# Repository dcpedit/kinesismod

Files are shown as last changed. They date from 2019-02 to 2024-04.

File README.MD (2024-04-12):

# Project moved to [Pillz Mod](https://github.com/dcpedit/pillzmod)
<p align="center">
  
</p>

This project has been replaced by Pillz Mod: https://github.com/dcpedit/pillzmod

# Kinesis Stapelberg Mod in KiCAD

kinesis-4

This is a fork of Aaron Silman's [kinesismod project](https://gitlab.com/Silman/kinesismod.git).  You can read more about it [on his blog](https://silman.io/project/kinesis_mod/)

This fork contains the following changes:

* Created a version that uses the Teensy 4.x
* Created a version that uses the STM32F411 Blackpill controller (`blackpill` directory)
* Use Vial firmware (`firmware` directory).
* Use ZMK firmware (`firmware` directory) wireless PillBug BLE option.

## USB Port

I recommend purchasing the following adapter from Amazon:
https://a.co/d/cRoqHqx

Here's how it looks like after installing:





## Wireless Bluetooth + ZMK
Bluetooth has been verified to work using the PillBug development board.  Below, you can see a 2000mAh 3.7V battery ([Amazon link](https://a.co/d/dVUdHxi)), as well as a 10mm push button ([Amazon link](https://a.co/d/5OVO4dY)) to disconnect the power when needed.



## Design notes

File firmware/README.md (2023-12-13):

# Firmware

## Vial (for Blackpill controller)
https://get.vial.today

Firmware source:
https://github.com/dcpedit/vial-qmk-dev/tree/vial/keyboards/dcpedit/kint_bp

File:
* `dcpedit_kint_bp_vial.bin`

## ZMK (for PillBug controller)
PillBug BLE development board:
https://mechwild.com/product/pillbug/

Firmware source:
https://github.com/dcpedit/zmk/tree/kinesispb/app/boards/shields/kinesispb

Files:
* `zmk_default.uf2` - Default keymap (stock Kinesis)
* `zmk_reset.uf2` - Resets PillBug board for BT connectivity issue on MacOS

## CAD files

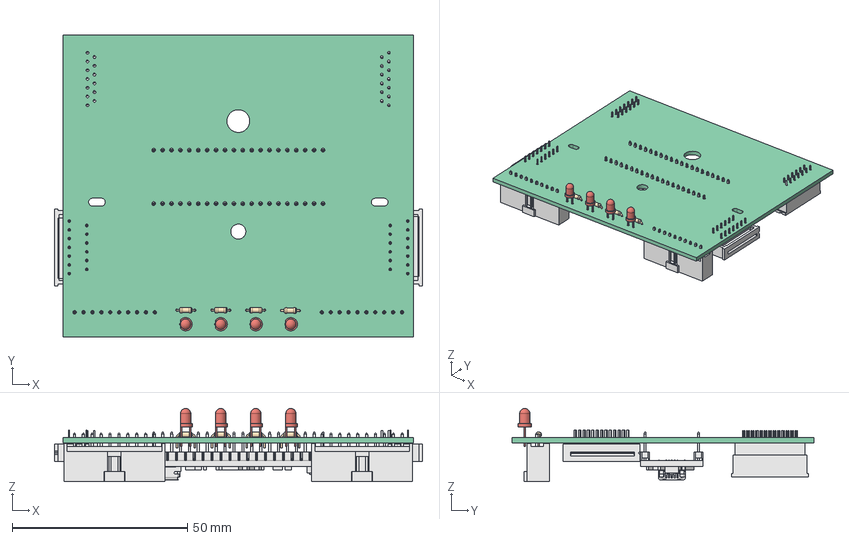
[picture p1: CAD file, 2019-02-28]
KinesisMod/board_model_FreeCAD.FCStd
104.9 x 86.0 x 20.9 mm
Pcb
D1_LED_D3.0mm_5C785324
D2_LED_D3.0mm_5C785337
D3_LED_D3.0mm_5C78534A
D4_LED_D3.0mm_5C78535D
R1_R_Axial_DIN0204_L36mm_D16mm_P508mm_Horizontal_5C785370
R2_R_Axial_DIN0204_L36mm_D16mm_P508mm_Horizontal_5C785383
R3_R_Axial_DIN0204_L36mm_D16mm_P508mm_Horizontal_5C785396
R4_R_Axial_DIN0204_L36mm_D16mm_P508mm_Horizontal_5C7853A9
J4_039532134_5C71893A
J3_039532134_5C718920
J1_039532135_5C7188EC
J2_039532135_5C718906
U1_Teensy++2.0_5C7189F9
J5_901361110_5C718957[2]
J6_901361110_5C718974[2]

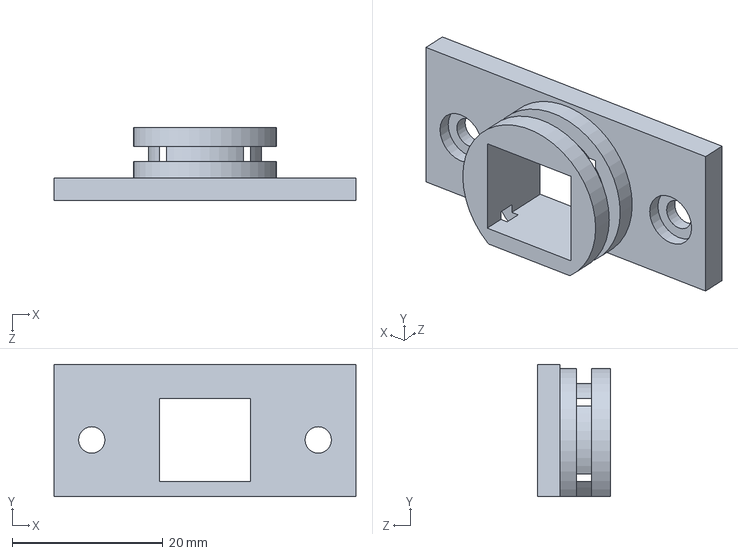
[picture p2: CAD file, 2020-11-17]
model/kinesis_usb_mount_with_reset.SLDPRT
40.0 x 17.5 x 9.70 mm

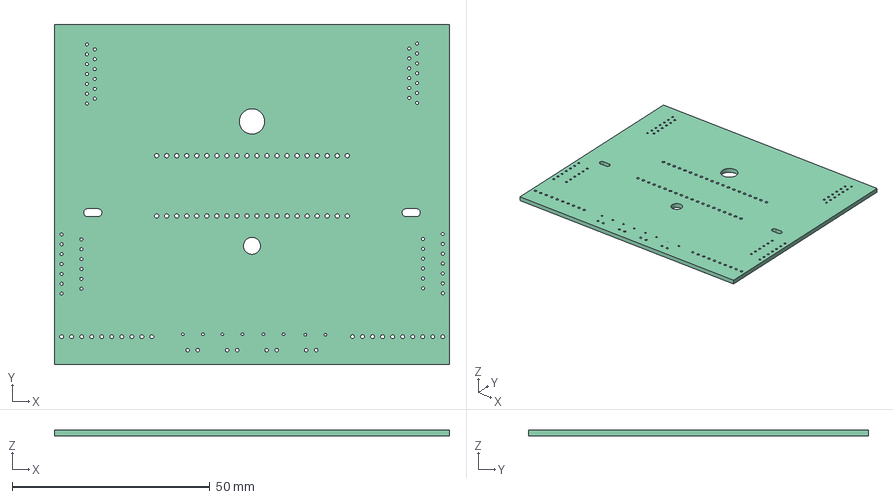
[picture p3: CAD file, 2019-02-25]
KinesisMod/boardModel.step
100.0 x 86.0 x 1.60 mm
Pcb
PCB_Sketch
Top

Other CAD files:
model/kinesis_usb_mount.SLDPRT
model/kinesis_ush_mount.STL
KinesisMod/boardModel.stl

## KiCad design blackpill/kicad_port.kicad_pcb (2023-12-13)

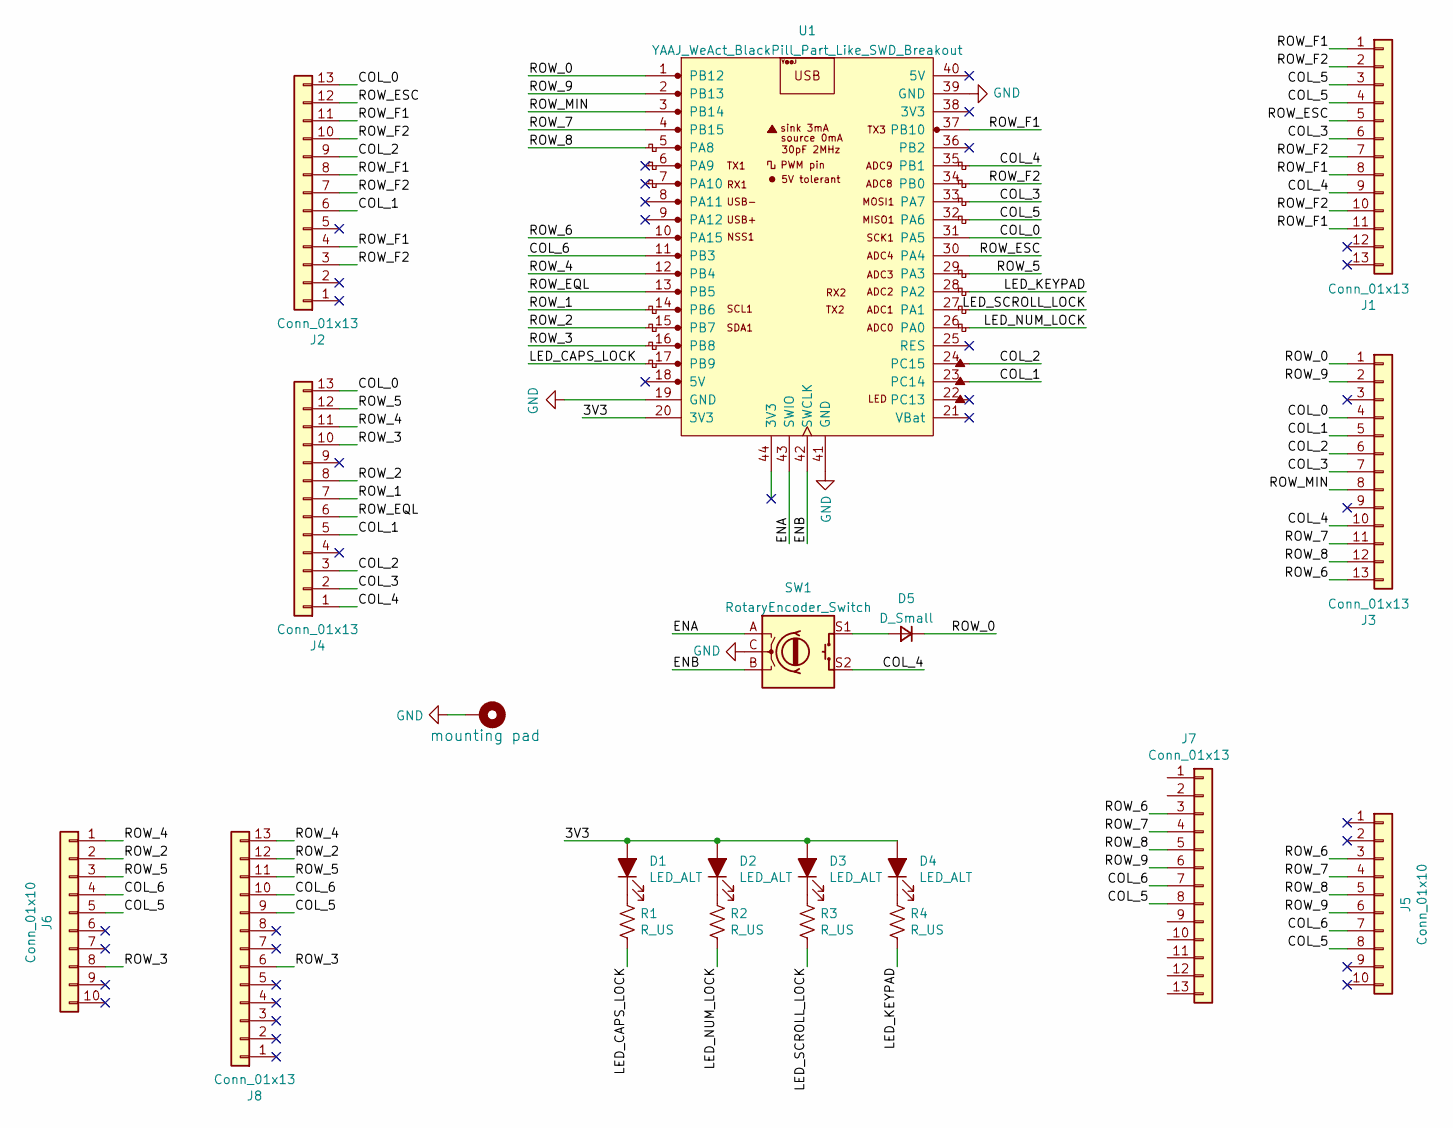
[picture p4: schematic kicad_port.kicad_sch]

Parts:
D1, D2, D3, D4: LED_ALT; LED_D3.0mm
D5: D_Small
H1: mounting pad; MountingHole_4.3mm_M4_Pad
J1, J2, J7, J8: Conn_01x13; Molex_0039532135
J3, J4: Conn_01x13; Molex_039532134
J5, J6: Conn_01x10; Pin_Header_Straight_1x10_Pitch2.54mm
R1, R2, R3, R4: R_US; R_Axial_DIN0204_L3.6mm_D1.6mm_P5.08mm_Horizontal
SW1: RotaryEncoder_Switch
U1: YAAJ_WeAct_BlackPill_Part_Like_SWD_Breakout; YAAJ_WeAct_BlackPill_SWD_2

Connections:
/3V3: D1.2 (A), D2.2 (A), D3.2 (A), D4.2 (A), U1.20 (3V3)
/COL_0: J2.13, J3.4, J4.13, U1.31 (PA5)
/COL_1: J2.6, J3.5, J4.5, U1.23 (PC14)
/COL_2: J2.9, J3.6, J4.3, U1.24 (PC15)
/COL_3: J1.6, J3.7, J4.2, U1.33 (PA7)
/COL_4: J1.9, J3.10, J4.1, SW1.S2, U1.35 (PB1)
/COL_5: J1.3, J1.4, J5.8, J6.5, J7.8, J8.9, U1.32 (PA6)
/COL_6: J5.7, J6.4, J7.7, J8.10, U1.11 (PB3)
/ENA: SW1.A, U1.43 (SWIO)
/ENB: SW1.B, U1.42 (SWCLK)
/LED_CAPS_LOCK: R1.2, U1.17 (PB9)
/LED_KEYPAD: R4.2, U1.28 (PA2)
/LED_NUM_LOCK: R2.2, U1.26 (PA0)
/LED_SCROLL_LOCK: R3.2, U1.27 (PA1)
/ROW_0: D5.1 (K), J3.1, U1.1 (PB12)
/ROW_1: J4.7, U1.14 (PB6)
/ROW_2: J4.8, J6.2, J8.12, U1.15 (PB7)
/ROW_3: J4.10, J6.8, J8.6, U1.16 (PB8)
/ROW_4: J4.11, J6.1, J8.13, U1.12 (PB4)
/ROW_5: J4.12, J6.3, J8.11, U1.29 (PA3)
/ROW_6: J3.13, J5.3, J7.3, U1.10 (PA15)
/ROW_7: J3.11, J5.4, J7.4, U1.4 (PB15)
/ROW_8: J3.12, J5.5, J7.5, U1.5 (PA8)
/ROW_9: J3.2, J5.6, J7.6, U1.2 (PB13)
/ROW_EQL: J4.6, U1.13 (PB5)
/ROW_ESC: J1.5, J2.12, U1.30 (PA4)
/ROW_F1: J1.1, J1.8, J1.11, J2.4, J2.8, J2.11, U1.37 (PB10)
/ROW_F2: J1.2, J1.7, J1.10, J2.3, J2.7, J2.10, U1.34 (PB0)
/ROW_MIN: J3.8, U1.3 (PB14)
GND: H1.1, SW1.C, U1.19 (GND), U1.39 (GND), U1.41 (GND)
unnamed: D1.1 (K), R1.1
unnamed: D2.1 (K), R2.1
unnamed: D3.1 (K), R3.1
unnamed: D4.1 (K), R4.1
unnamed: D5.2 (A), SW1.S1

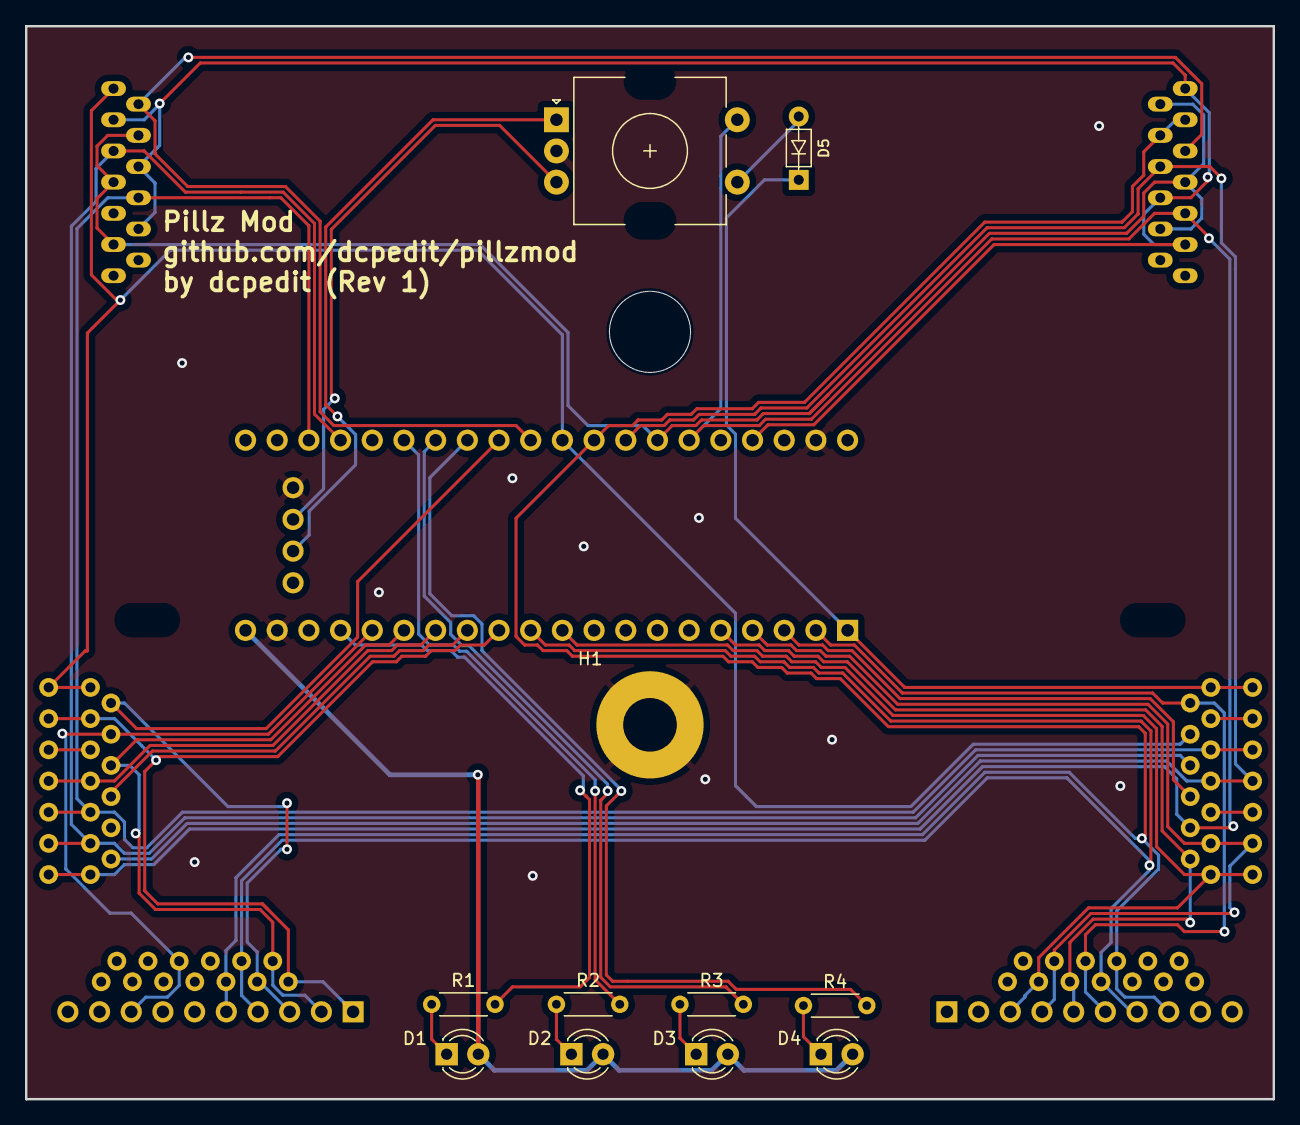
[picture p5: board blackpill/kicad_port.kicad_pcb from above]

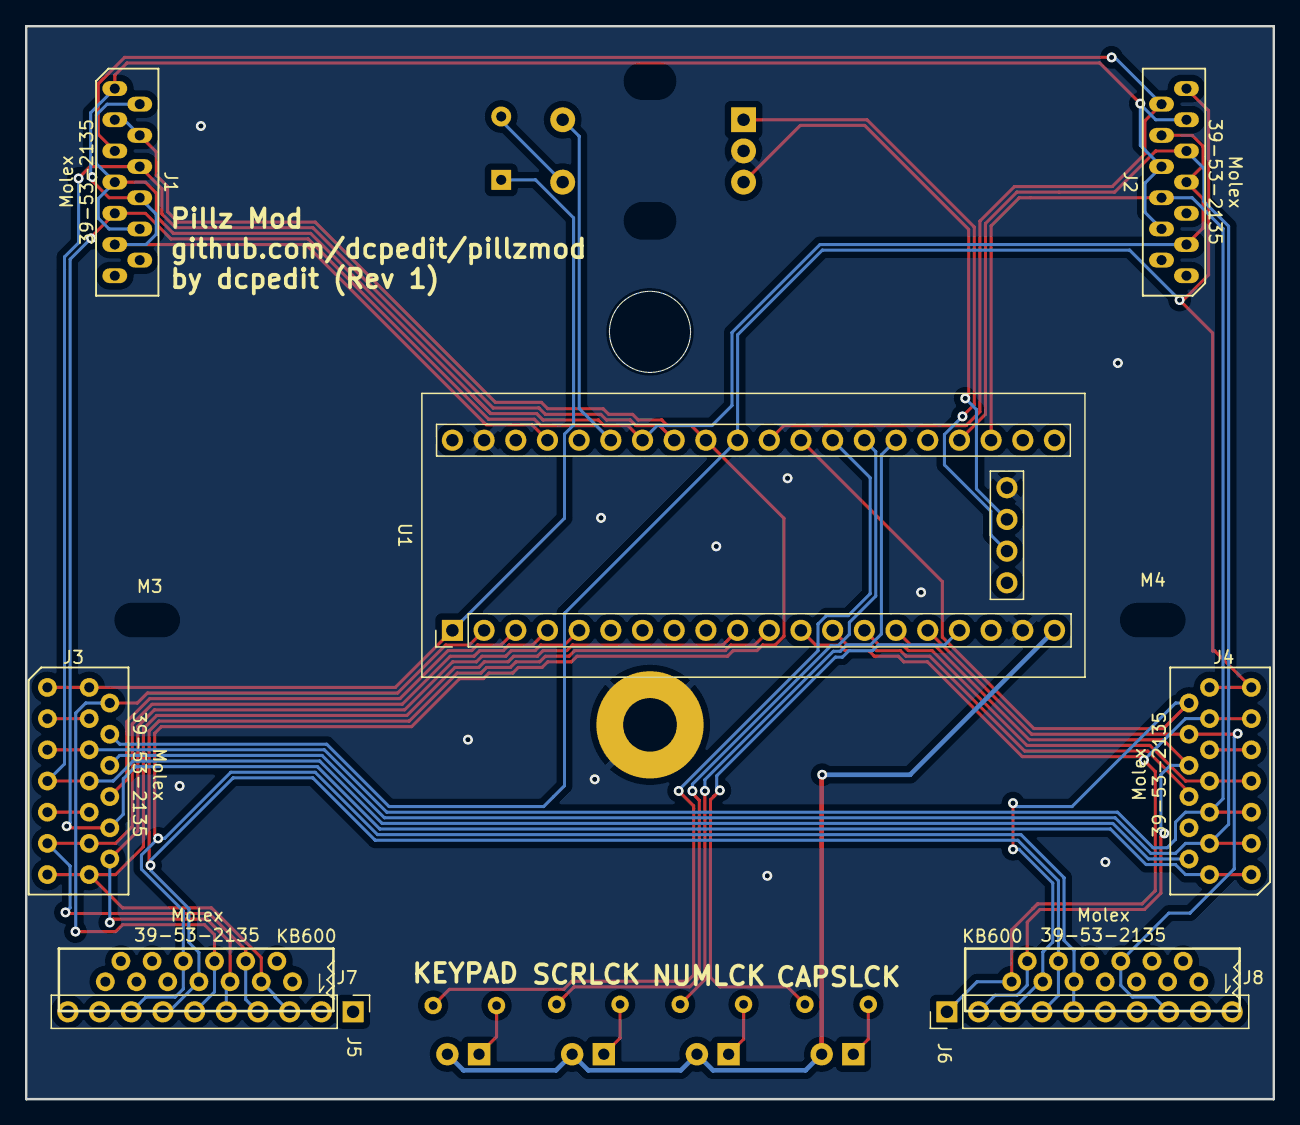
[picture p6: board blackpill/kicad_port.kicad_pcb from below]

Board: 2 copper layers, 100.0 x 86.0 mm, 23 parts (12 on the bottom side), 35 nets.

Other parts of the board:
M1: MountingHole_6.4mm_M6
M3, M4: MountingHole_4.3mm_M4

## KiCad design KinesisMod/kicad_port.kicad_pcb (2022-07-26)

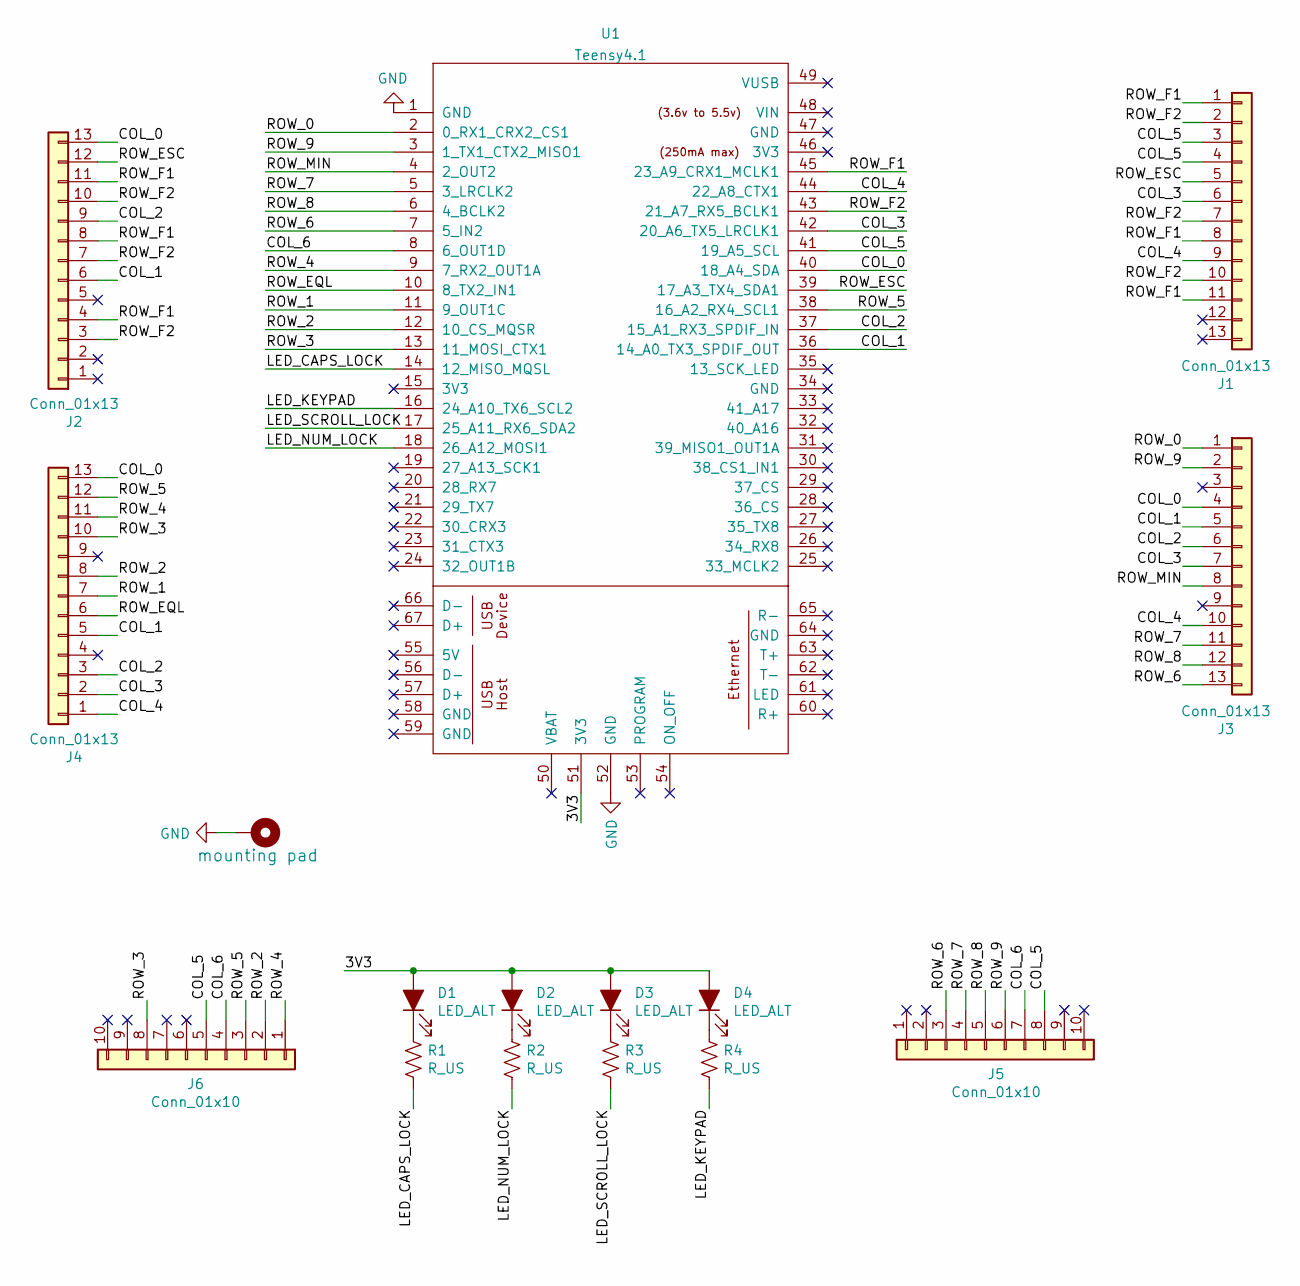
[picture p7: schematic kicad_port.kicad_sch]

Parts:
D1, D2, D3, D4: LED_ALT; LED_D3.0mm
H1: mounting pad; MountingHole_4.3mm_M4_Pad
J1, J2: Conn_01x13; Molex_0039532135
J3, J4: Conn_01x13; Molex_039532134
J5, J6: Conn_01x10; Pin_Header_Straight_1x10_Pitch2.54mm
R1, R2, R3, R4: R_US; R_Axial_DIN0204_L3.6mm_D1.6mm_P5.08mm_Horizontal
U1: Teensy4.1; Teensy41

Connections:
/3V3: D1.2 (A), D2.2 (A), D3.2 (A), D4.2 (A), U1.51 (3V3)
/COL_0: J2.13, J3.4, J4.13, U1.40 (18_A4_SDA)
/COL_1: J2.6, J3.5, J4.5, U1.36 (14_A0_TX3_SPDIF_OUT)
/COL_2: J2.9, J3.6, J4.3, U1.37 (15_A1_RX3_SPDIF_IN)
/COL_3: J1.6, J3.7, J4.2, U1.42 (20_A6_TX5_LRCLK1)
/COL_4: J1.9, J3.10, J4.1, U1.44 (22_A8_CTX1)
/COL_5: J1.3, J1.4, J5.8, J6.5, U1.41 (19_A5_SCL)
/COL_6: J5.7, J6.4, U1.8 (6_OUT1D)
/LED_CAPS_LOCK: R1.2, U1.14 (12_MISO_MQSL)
/LED_KEYPAD: R4.2, U1.16 (24_A10_TX6_SCL2)
/LED_NUM_LOCK: R2.2, U1.18 (26_A12_MOSI1)
/LED_SCROLL_LOCK: R3.2, U1.17 (25_A11_RX6_SDA2)
/ROW_0: J3.1, U1.2 (0_RX1_CRX2_CS1)
/ROW_1: J4.7, U1.11 (9_OUT1C)
/ROW_2: J4.8, J6.2, U1.12 (10_CS_MQSR)
/ROW_3: J4.10, J6.8, U1.13 (11_MOSI_CTX1)
/ROW_4: J4.11, J6.1, U1.9 (7_RX2_OUT1A)
/ROW_5: J4.12, J6.3, U1.38 (16_A2_RX4_SCL1)
/ROW_6: J3.13, J5.3, U1.7 (5_IN2)
/ROW_7: J3.11, J5.4, U1.5 (3_LRCLK2)
/ROW_8: J3.12, J5.5, U1.6 (4_BCLK2)
/ROW_9: J3.2, J5.6, U1.3 (1_TX1_CTX2_MISO1)
/ROW_EQL: J4.6, U1.10 (8_TX2_IN1)
/ROW_ESC: J1.5, J2.12, U1.39 (17_A3_TX4_SDA1)
/ROW_F1: J1.1, J1.8, J1.11, J2.4, J2.8, J2.11, U1.45 (23_A9_CRX1_MCLK1)
/ROW_F2: J1.2, J1.7, J1.10, J2.3, J2.7, J2.10, U1.43 (21_A7_RX5_BCLK1)
/ROW_MIN: J3.8, U1.4 (2_OUT2)
GND: H1.1, U1.1 (GND), U1.52 (GND)
unnamed: D1.1 (K), R1.1
unnamed: D2.1 (K), R2.1
unnamed: D3.1 (K), R3.1
unnamed: D4.1 (K), R4.1

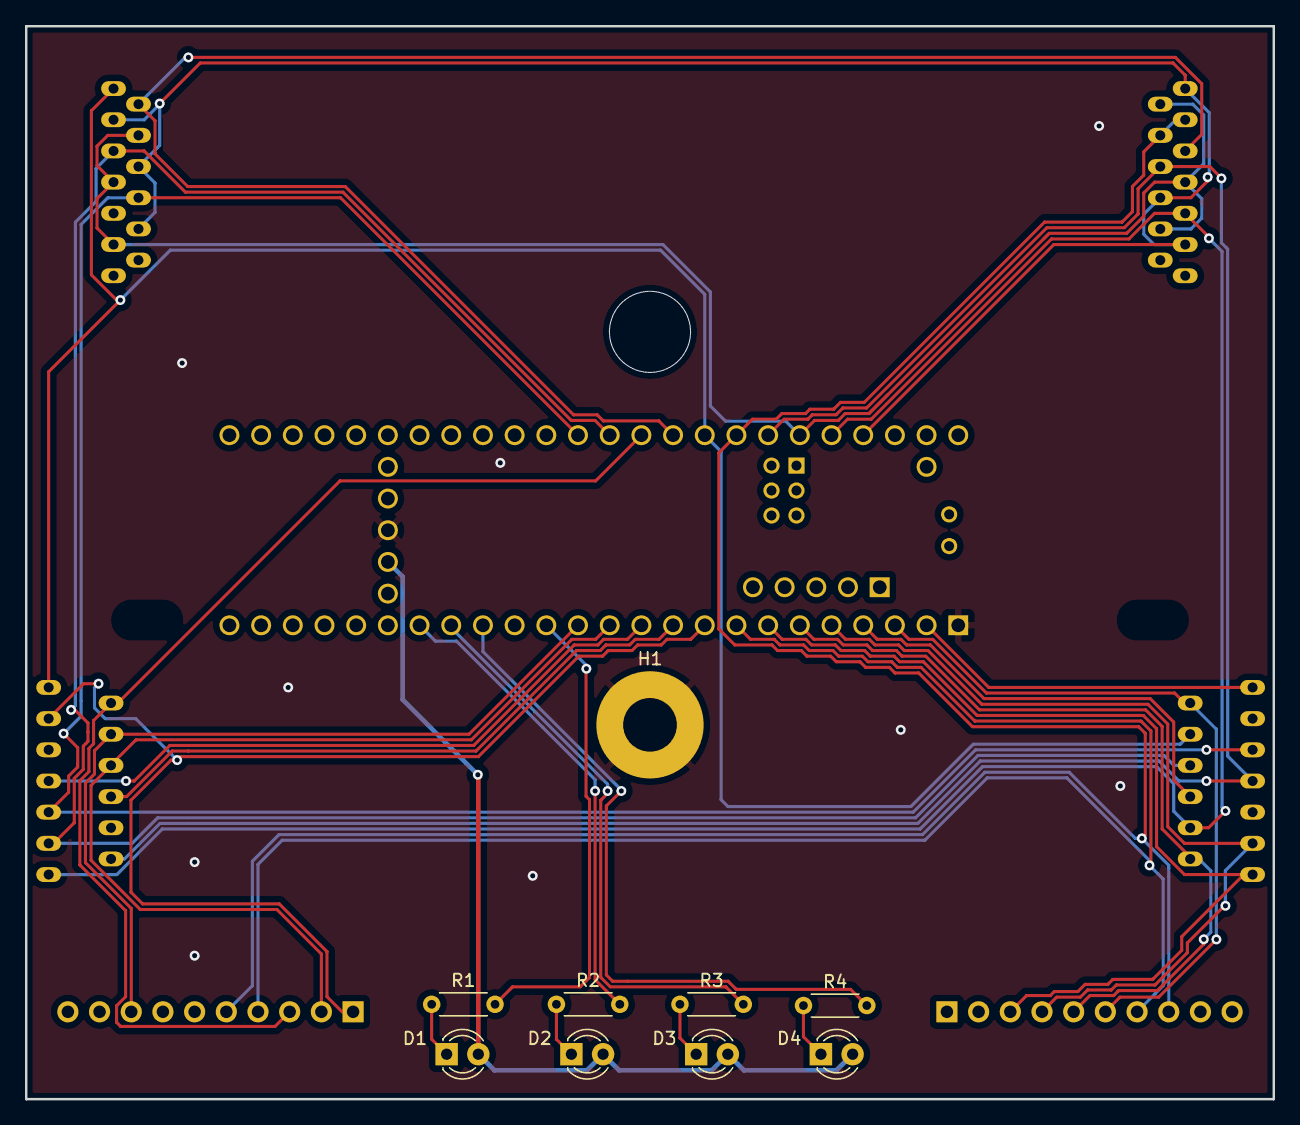
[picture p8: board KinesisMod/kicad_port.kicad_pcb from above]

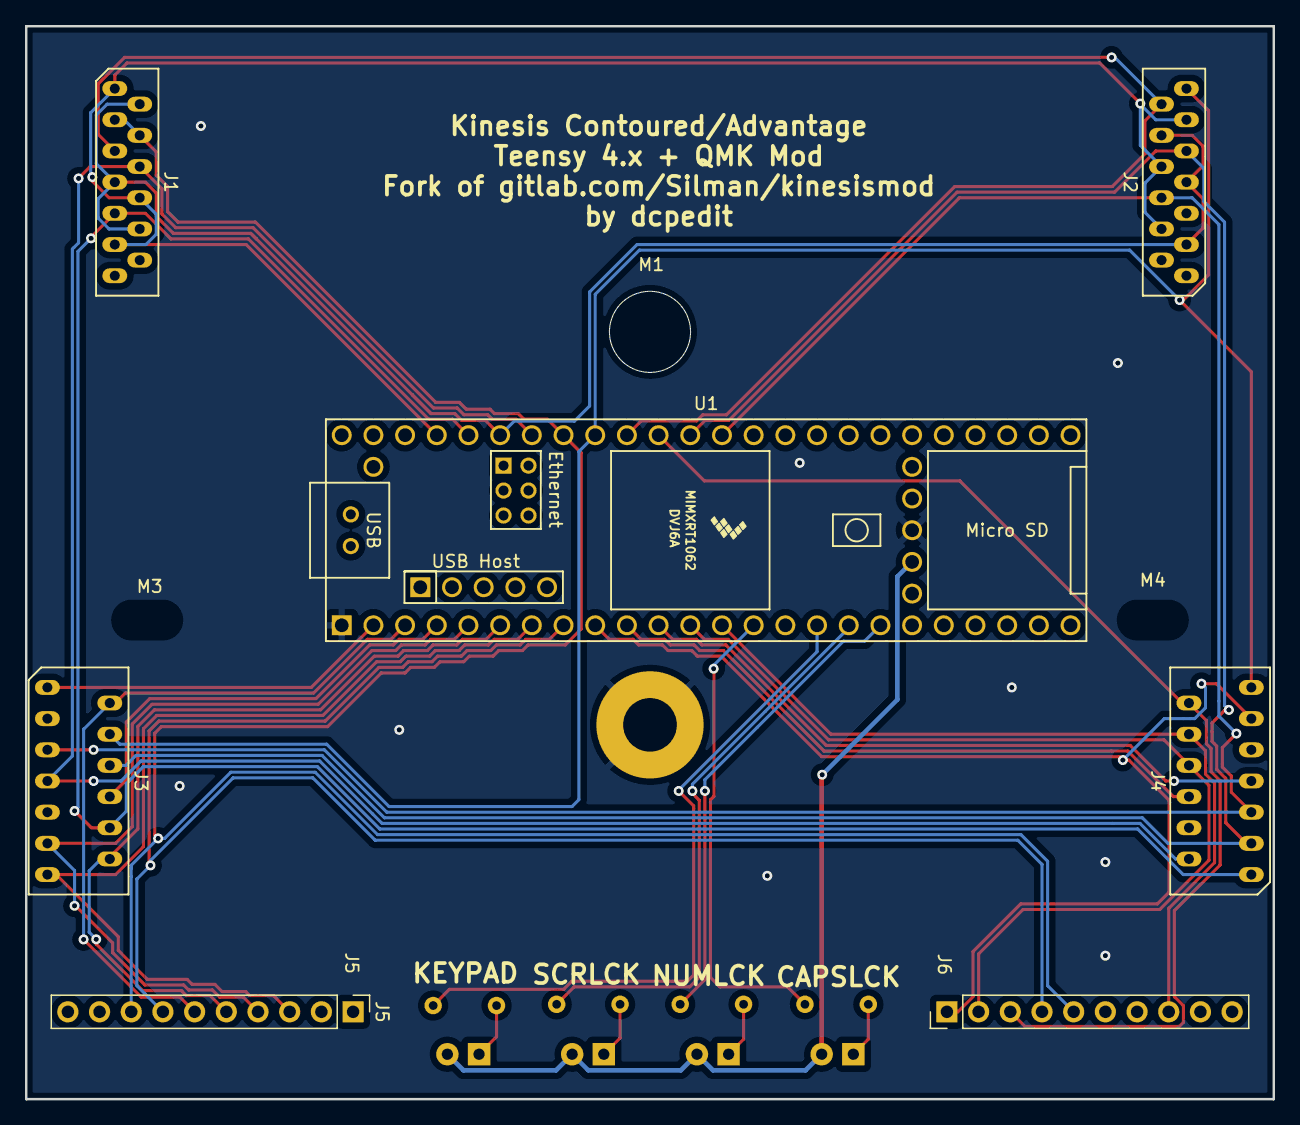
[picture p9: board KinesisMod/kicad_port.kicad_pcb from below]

Board: 2 copper layers, 100.0 x 86.0 mm, 19 parts (10 on the bottom side), 32 nets.

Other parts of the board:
M1: MountingHole_6.4mm_M6
M3, M4: MountingHole_4.3mm_M4

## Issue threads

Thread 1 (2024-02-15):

Adding extra more buttons to your version?

LeoMegaAir, 2024-02-15:
Hi dcpedit, I'm new to all this so please bear with me.

_This is not an issue_, it's a question but I couldn't find a way to ask a question here. My Kinesis has seven extra buttons (the original Kinesis controller has some extra lines so [all people do it](https://geekhack.org/index.php?topic=36195.msg2252517#msg2252517)).

Would it be possible to retain those extra buttons if I get rid of the original controller and use yours?
Another question would be, the [blackpill folder](https://github.com/dcpedit/kinesismod/tree/master/blackpill) contains so many files - which of them am I supposed to use to order a PCB on JLCPCB?

dcpedit, 2024-02-15:
The [kinesismod_blackpill.zip](https://github.com/dcpedit/kinesismod/blob/master/blackpill/kinesismod_blackpill.zip) is the file you'll want to upload to JLCPCB.

As for the extra buttons, theoretically you can get them to work, but you will need to wire them up correctly.  There's room in the matrix for extra keys, so you'll can use the unused slots, but make sure the row pin is connected to a diode.  See the firmware source files for how the matrix is wired:

https://github.com/dcpedit/vial-qmk-dev/blob/vial/keyboards/dcpedit/kint_bp/kint_bp.h

Pin assignments:

https://github.com/dcpedit/vial-qmk-dev/blob/vial/keyboards/dcpedit/kint_bp/config.h

Closed 2024-03-20.

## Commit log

2019-02-18 initial commit, schematic done, custom molex and teensy footprints done
    [brd_to_kicad.kicad_pcb, brd_to_kicad.sch, kicad_port.kicad_pcb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]
2019-02-18 layout begun
    [kicad_port.kicad_pcb]
2019-02-19 change LED and Resistor footprints
    [kicad_port.kicad_pcb, kicad_port.sch]
2019-02-19 modify led position
    [kicad_port.kicad_pcb]
2019-02-19 add dimensions to converted board, transferred to ported board
    [brd_to_kicad.kicad_pcb, kicad_port.kicad_pcb]
2019-02-21 add FreeCAD board model
    [board_Model.FCStd]
2019-02-21 change dimensions alignment
    [kicad_port.kicad_pcb]
2019-02-21 refactor folder locations
    [board_Model.FCStd, brd_to_kicad.kicad_pcb, brd_to_kicad.sch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]
2019-02-25 first pass auto-routed with FreeRouting.jar, should probably re-orient some stuff (LEDS) and do another pass. Board has been 3D printed and checked for size compatibility with case and keywells
    [boardModel.step, boardModel.stl, board_Model.FCStd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]
2019-02-25 re-routed with LEDs flipped onto other side of board
    [kicad_port.kicad_pcb]
2019-02-25 realized J1 and J2 were swapped and J3 and J4 were swapped. Replced and re-routed
    [kicad_port.kicad_pcb]
2019-02-25 parts were not on correct side of board, had to re-orient and re-route. In addition I added the 3d Models for the other parts
    [039532134.stp, 039532135.stp, kicad_port.kicad_pcb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]
2019-02-25 add labels for LEDs
    [kicad_port.kicad_pcb]
2019-02-26 add actual 10-pin header model and moved parts over so they arent hanging off board, re-routed
    [901361110.stp, kicad_port.kicad_pcb]
2019-02-26 slight board edit and double checking all pins. Should be good to send to fab after adding more Silk
    [kicad_port.kicad_pcb]
2019-02-27 re-placed F-row connectors closer to edge, re-routed
    [kicad_port.kicad_pcb]
2019-02-28 sent board files to fab
    [boardModel.stl, board_model_FreeCAD.FCStd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]
2019-07-18 add detail to README and add warning REAME to the auto generated kiCAD
2020-07-14 add usb mount model to repo
    [kinesis_ush_mount.STL]
2020-11-17 remove brd_to_kicad folder, add my own qmk firmware keymap
    [brd_to_kicad.kicad_pcb, brd_to_kicad.sch, kinesis_usb_mount.SLDPRT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]
2022-07-26 Modify to support Teensy 4.x
    [kicad_port-B_Cu.gbl, kicad_port-B_Mask.gbs, kicad_port-B_Paste.gbp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]
2022-08-14 Add blackpill edition
    [039532134.stp, 039532135.stp, 901361110.stp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]
2022-08-14 Add promicro support
    [039532134.stp, 039532135.stp, 901361110.stp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]
2022-08-22 File cleanup
    [kicad_port-B.Cu.GBL, kicad_port-B.Mask.GBS, kicad_port-B.SilkS.GBO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]
2022-08-22 Add Promicro
    [kicad_port-B.Cu.GBL, kicad_port-B.Mask.GBS, kicad_port-B.SilkS.GBO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]
2022-08-23 File for acrylic plate
2022-08-25 Add Advantage compatibility
    [kicad_port.kicad_pcb, kicad_port.kicad_sch]
2023-12-13 Update readme with wireless info
    [kicad_port-B_Cu.gbl, kicad_port-B_Mask.gbs, kicad_port-B_Paste.gbp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]
2023-12-13 Remove promicro dev
    [kicad_port-B.Cu.GBL, kicad_port-B.Mask.GBS, kicad_port-B.SilkS.GBO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]
